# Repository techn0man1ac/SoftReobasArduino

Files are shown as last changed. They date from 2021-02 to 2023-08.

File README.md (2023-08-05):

# ATmega8/Arduino Nano reobas

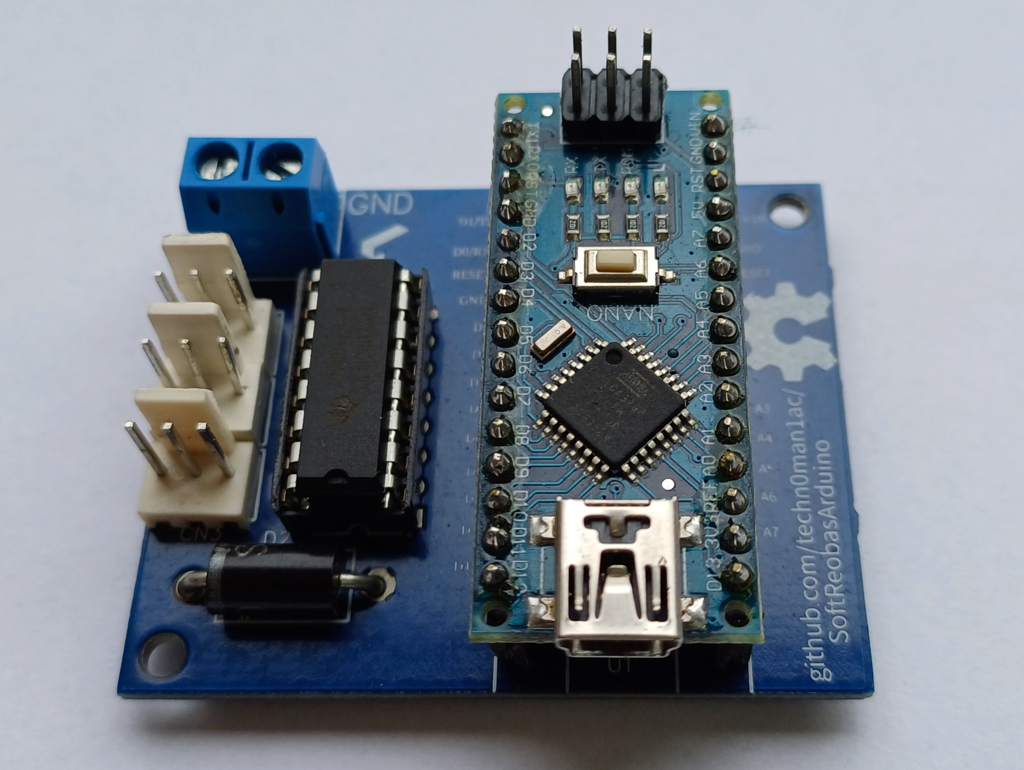
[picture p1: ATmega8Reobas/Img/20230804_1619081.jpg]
PCB board photo Board photo


This project is a controller for three standard PC fans, controlled by a computer program(Windows 7/10 tested). Video with a demonstration:

https://youtu.be/29GA7r1BqcI

# Schematic:

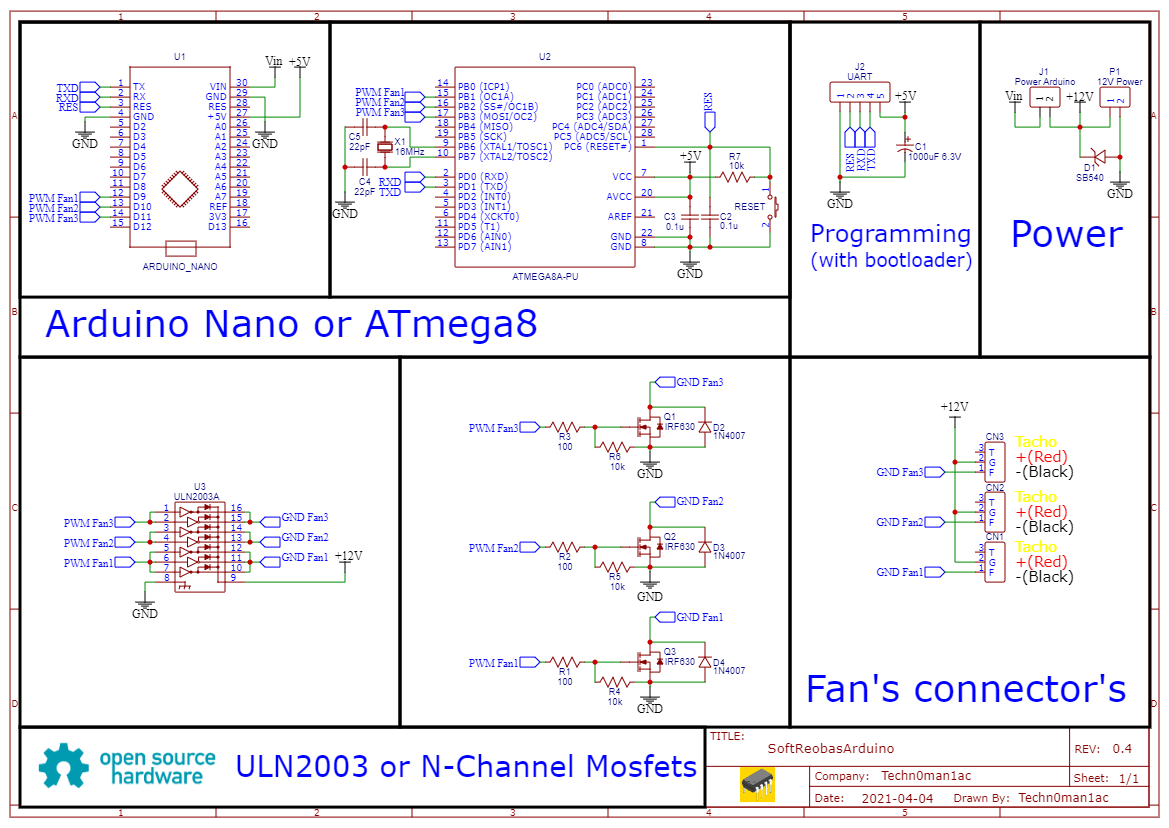
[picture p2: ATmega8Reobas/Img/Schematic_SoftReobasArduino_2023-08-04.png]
Schematic ATmega8/ArduinoNano


Schematics provide two versions of the board, one - using Arduino Nano and ULN2003(Darlington transistors package), first photo from upper, and second - using ATmega8 CPU and three MOSFET transistors in the TO-220 case(for example IRF540/IRF640/IRF740). 

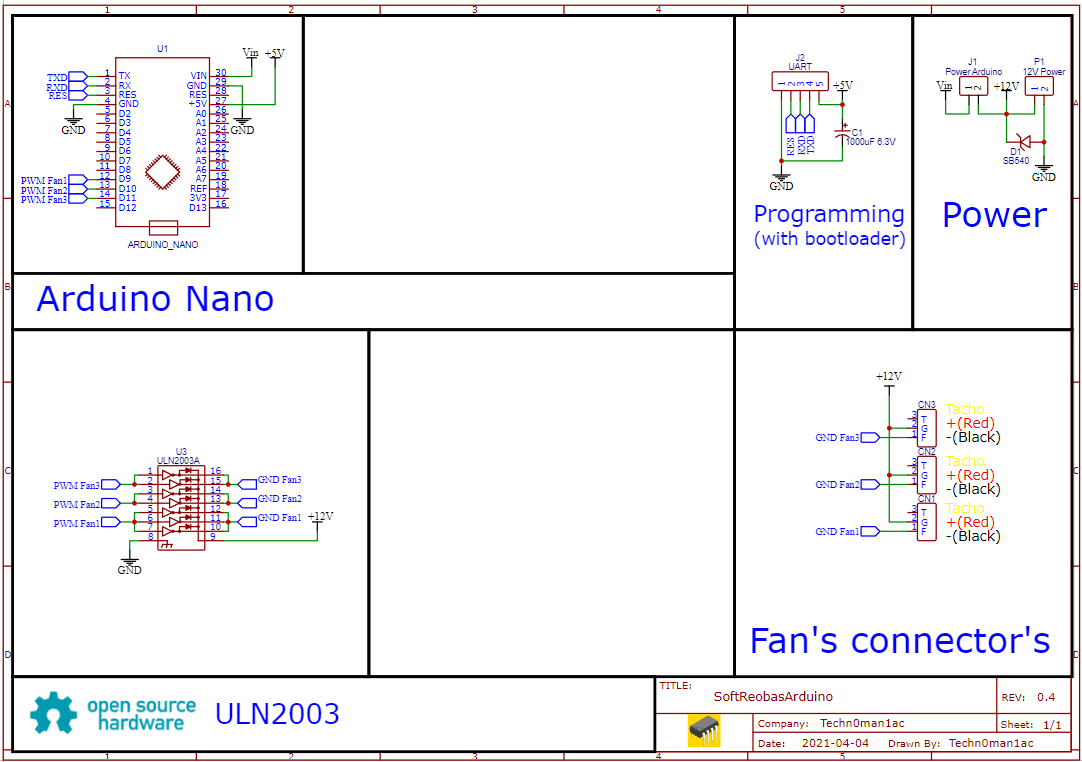
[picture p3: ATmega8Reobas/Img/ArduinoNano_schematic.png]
Schematic with ArduinoNano


I developed only the first one in PCB format, the second remained in prototype format(last photo). I like the first option because ULN2003 is popular chip that integrates everything from current-limiting resistors to protection diodes in a circuit that only requires a few components:

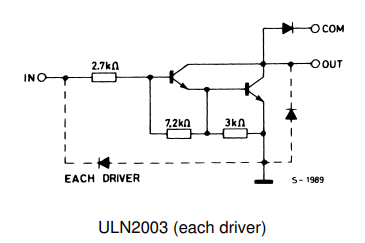
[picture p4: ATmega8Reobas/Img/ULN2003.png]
ULN2003 structure


According to the documentation for ULN2003, the chip can output 500mA per channel, if you look at my schematic, you will see that I have paralleled two outputs for the FAN2 and FAN3 - they can output up to 1000mA per fan, and fan1 has three outputs connected in parallel, correspondingly, the output current can be up to 1500 mA, that is, a more powerful fan can be connected here. However, MOSFET solutions can produce several times more output currents.

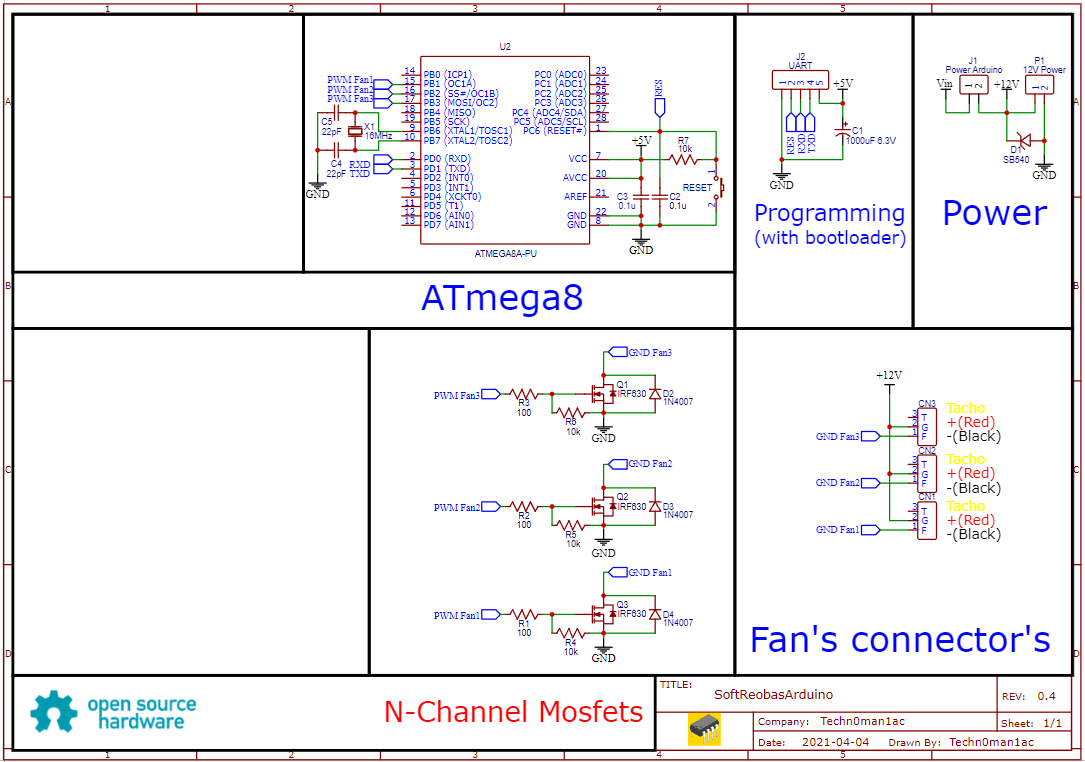
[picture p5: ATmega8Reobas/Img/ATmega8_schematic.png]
MOSFET solution


You can use both solutions, Arduino Nano or ATmega8, but in the case of ATmega8, you need pre-flash the firmware(with Arduino IDE) and next step - connect a USB-UART adapter to J2 (baud rate 9600), ATmega8 solutuon - need supply +5V for the J2, Arduino Nano have all this in board.

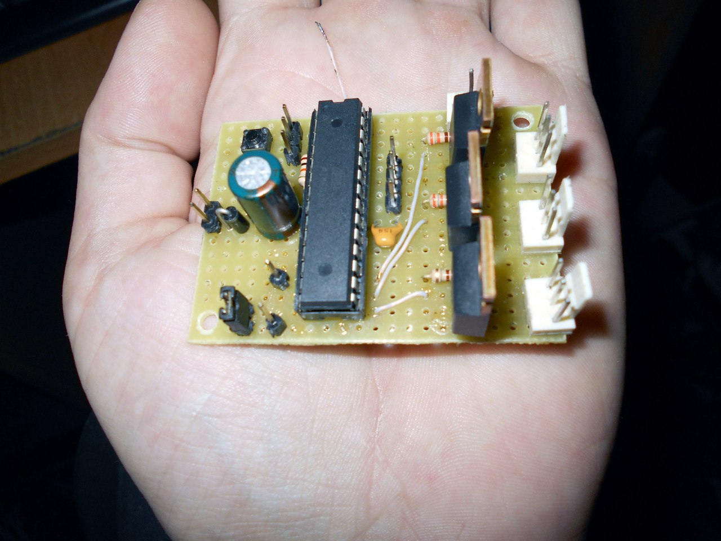
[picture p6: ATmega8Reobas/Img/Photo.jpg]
Schematic ATmega8/ArduinoNano


And last - in case ATmega8 you need to know how to Program an AVR Board Using an Arduino Board:

[https://www.instructables.com/How-to-program-a-AVR-arduino-with-another-arduin/](https://www.instructables.com/How-to-Program-an-AVR-Board-Using-an-Arduino-Board/)

# PCB:

The front:

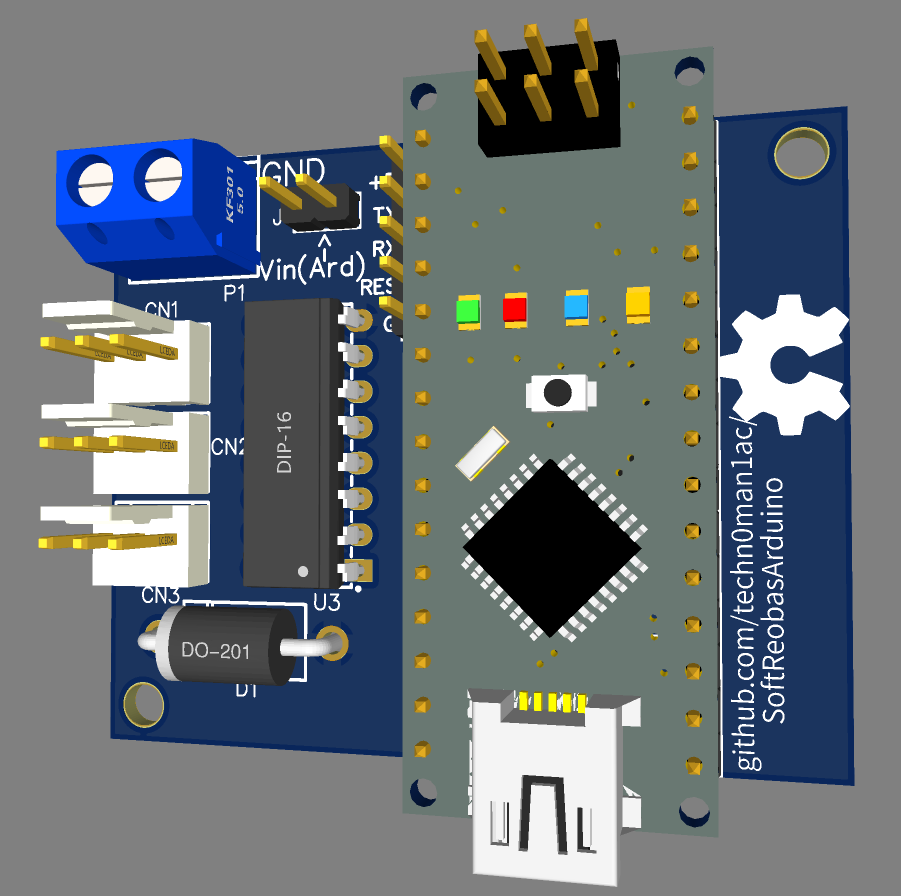
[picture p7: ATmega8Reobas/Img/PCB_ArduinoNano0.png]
ArduinoNano ULN2003 PCB render0


Bottom side:

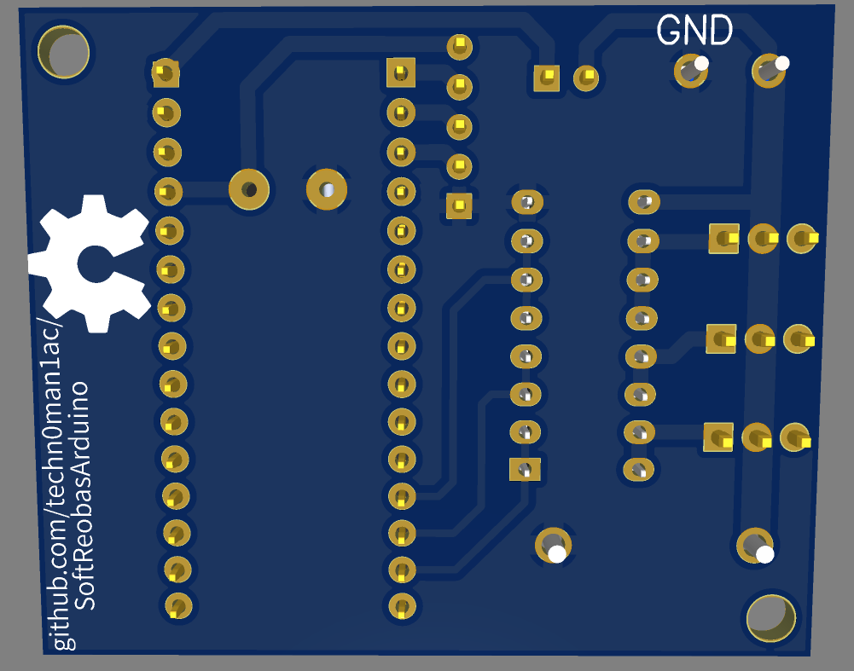
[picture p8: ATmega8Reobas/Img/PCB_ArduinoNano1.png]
ArduinoNano ULN2003 PCB render1


Board dimensions:

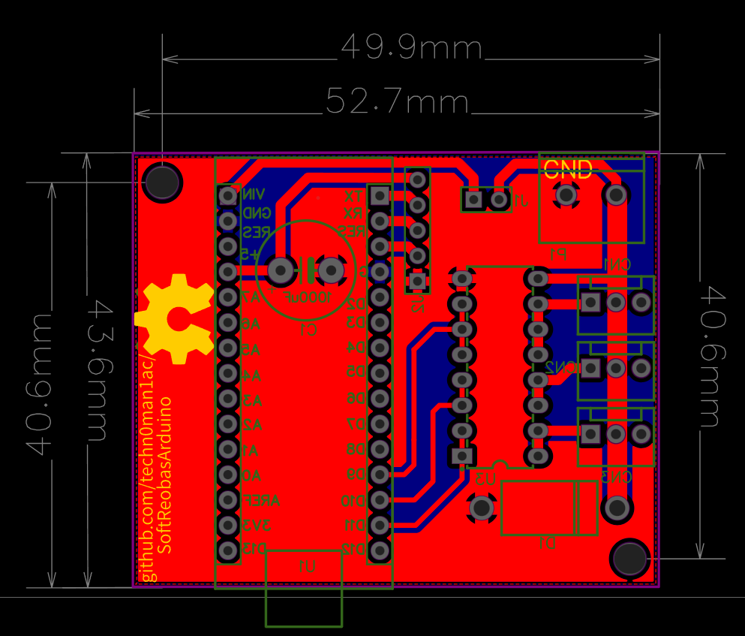
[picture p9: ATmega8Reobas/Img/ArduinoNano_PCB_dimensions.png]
ArduinoNano PCB dimensions ArduinoNano ArduinoNano PCB dimensions


Gerber files for order PCB here:

https://github.com/techn0man1ac/SoftReobasArduino/tree/main/ATmega8Reobas/PCB/Gerbers

Project (circuit and PCB) on EasyEDA(OSHWlab):

https://oshwlab.com/raznie.podelki/softreobasarduino

# Arduino IDE:

Source code for Arduino IDE:

https://github.com/techn0man1ac/SoftReobasArduino/tree/main/ATmega8Reobas/Code/Arduino%20IDE/SoftReobasArduino

As a CPU, you can use both, ATmega8 or Arduino Nano (by default, the code is selected for Arduino Nano, or ATmega328), if you use ATmega8 CPU, you need to comment out lines 15,16,18,19 and uncomment lines 24 and 25, as in the picture below:

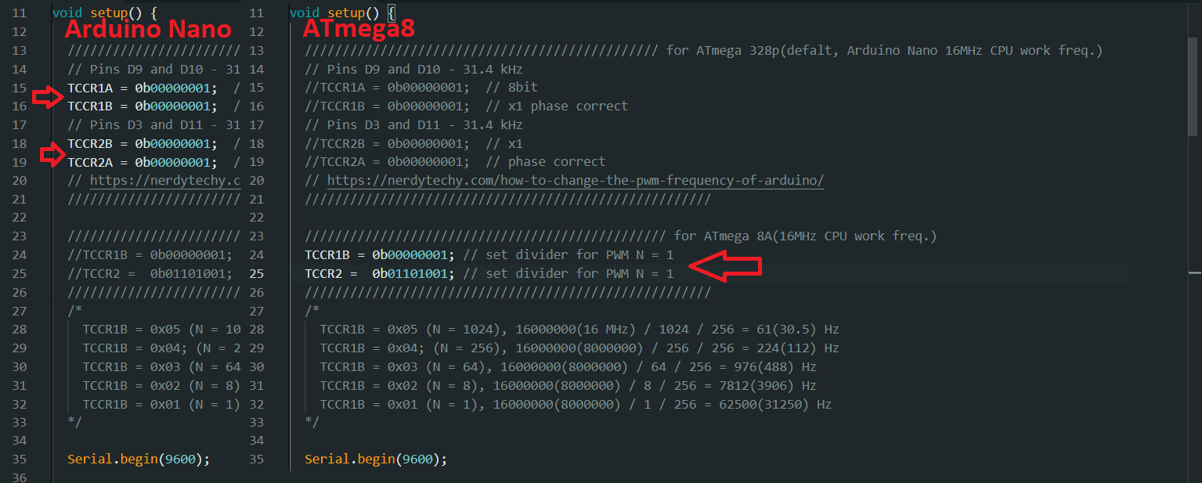
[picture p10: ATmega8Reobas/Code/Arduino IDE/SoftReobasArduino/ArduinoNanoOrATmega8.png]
ATmega8 or Arduino Nano ATmega8 or Arduino Nano


These lines set the PWM frequency at 31 kHz (so that the squeak of the fans is not heard), provided that the controller is clocked at a frequency of 16 MHz.
The only thing is that the ATmega8 must operate at a frequency of 16 MHz, that is, it must be clocked from an external quartz.

# Windows application:
 
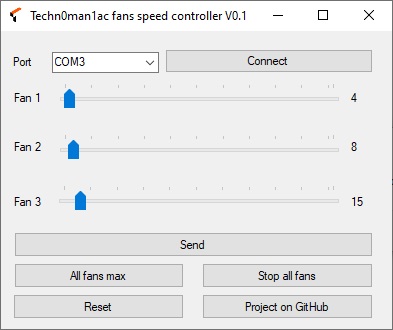
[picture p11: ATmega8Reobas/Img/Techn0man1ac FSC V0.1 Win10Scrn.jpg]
Windows10 screenshot app


The "Techn0man1ac FSC V0.1" program for PC (tested on Windows 7/10) works as - connect the board to the computer, run program and select "Port" in the drop-down list (top left), choose the number of the USB-UART COM port of the hardware converter, click " Connect" - well done, you can send commands to the board using the user interface buttons:
- "Send" - sends the current values set by the "Fan 1", "Fan 2", "Fan 3" sliders (default is 127, displayed to the right of the slider) to the microcontroller, which stores these values in its EEPROM (non-volatile memory), that is, even after restart the controller will remember this values;
- "All fans max" - this button gives the maximum speed for all fans (also written to EEPROM);
- "Stop all fans" - full stop(without write into EEPROM);
- "Reset" - restart the board;
- "Project on GitHub" - a button that brings the user here to the project page.

Download program "Techn0man1ac FSC V0.1":

https://github.com/techn0man1ac/ATmega8Reobas/tree/main/ATmega8Reobas/WinApp

# Protocol

The protocol of interaction is very simple - the program sends into COM every second the position of each slider in the format d127.64.255 and 127 is the speed of FAN1(CN1), 64 - FAN2(CN2), 255 - FAN3(CN3) but speed is 0..255 like 0..100%, where 255 is 100%.

- If program send "m" - presed button "All fans max";
- "s" - presed button "Stop all fans";
-  "r" - presed button "Reset".

CPU recognized its and do some magic - easy peasy, lemon squeeze ;)

# С# sourse code:

Program write on С# in "Microsoft Visual Studio Community 2019 V16.9.2", PS program source code - Fans speed controller(Windows):

https://github.com/techn0man1ac/ATmega8Reobas/tree/main/ATmega8Reobas/Code/Fans%20speed%20controller(Windows)/WindowsFormsApplication1

# Proteus 8 simulation:

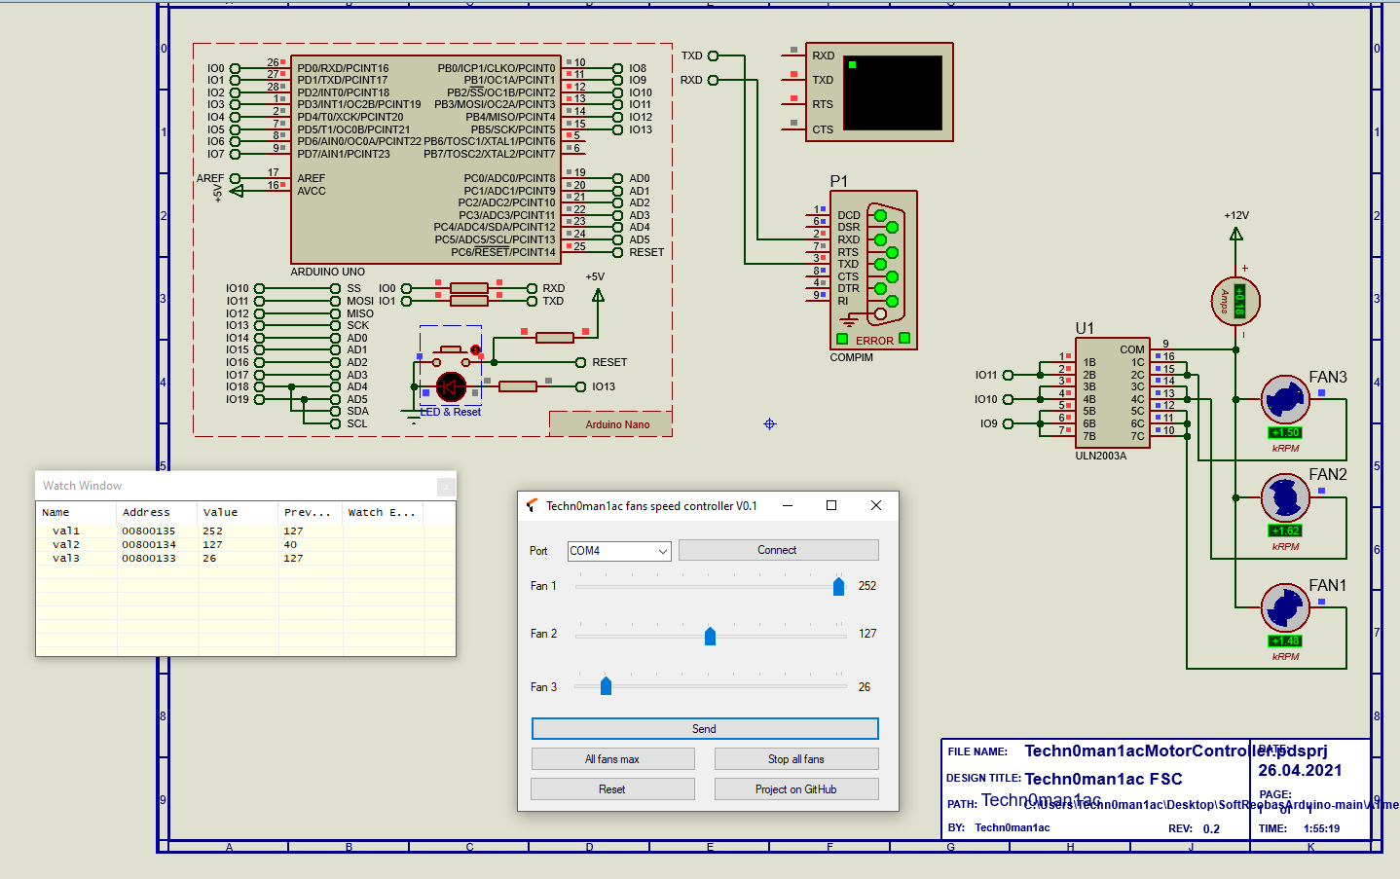
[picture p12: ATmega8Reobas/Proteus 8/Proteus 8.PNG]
Proteus 8 simulation


Project have Proteus 8 files and full simulate:

https://github.com/techn0man1ac/SoftReobasArduino/tree/main/ATmega8Reobas/Proteus%208

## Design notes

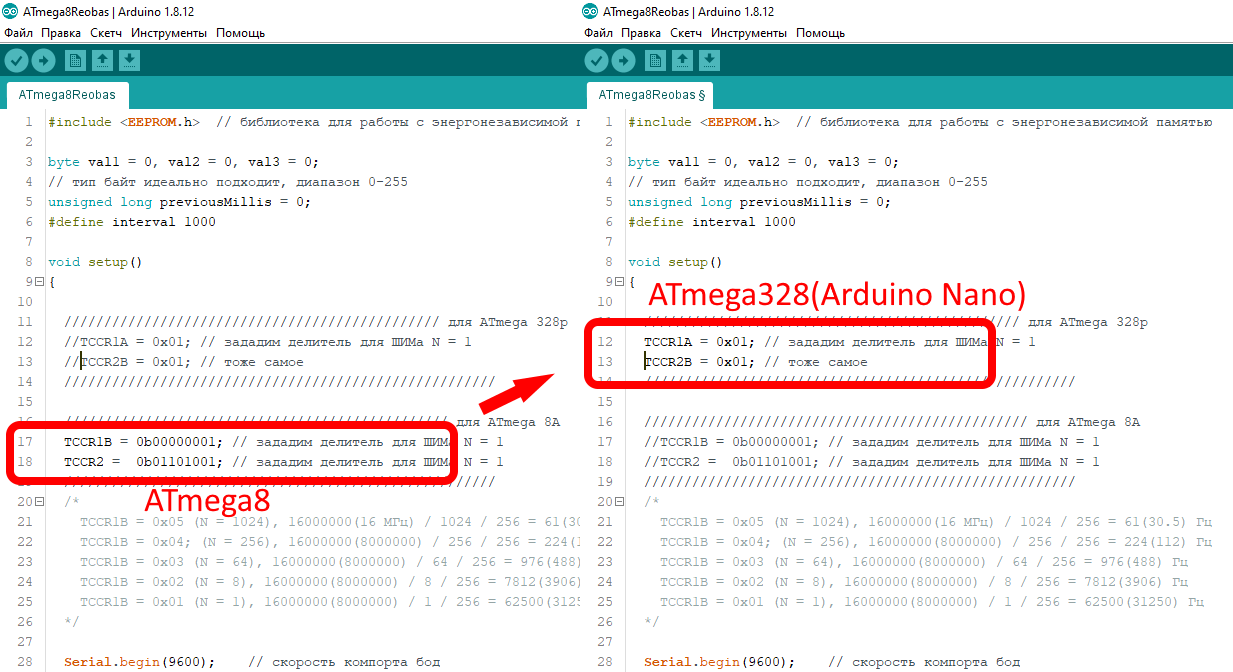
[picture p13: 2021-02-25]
ATmega8Reobas/Img/8or328.png

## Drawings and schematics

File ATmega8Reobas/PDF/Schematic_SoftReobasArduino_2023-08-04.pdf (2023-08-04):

A7 | 19 A6 | 20 A5 | 21 A4 | 22 A3 | 23 A2 | 24 A1 | 25 A0 | 26

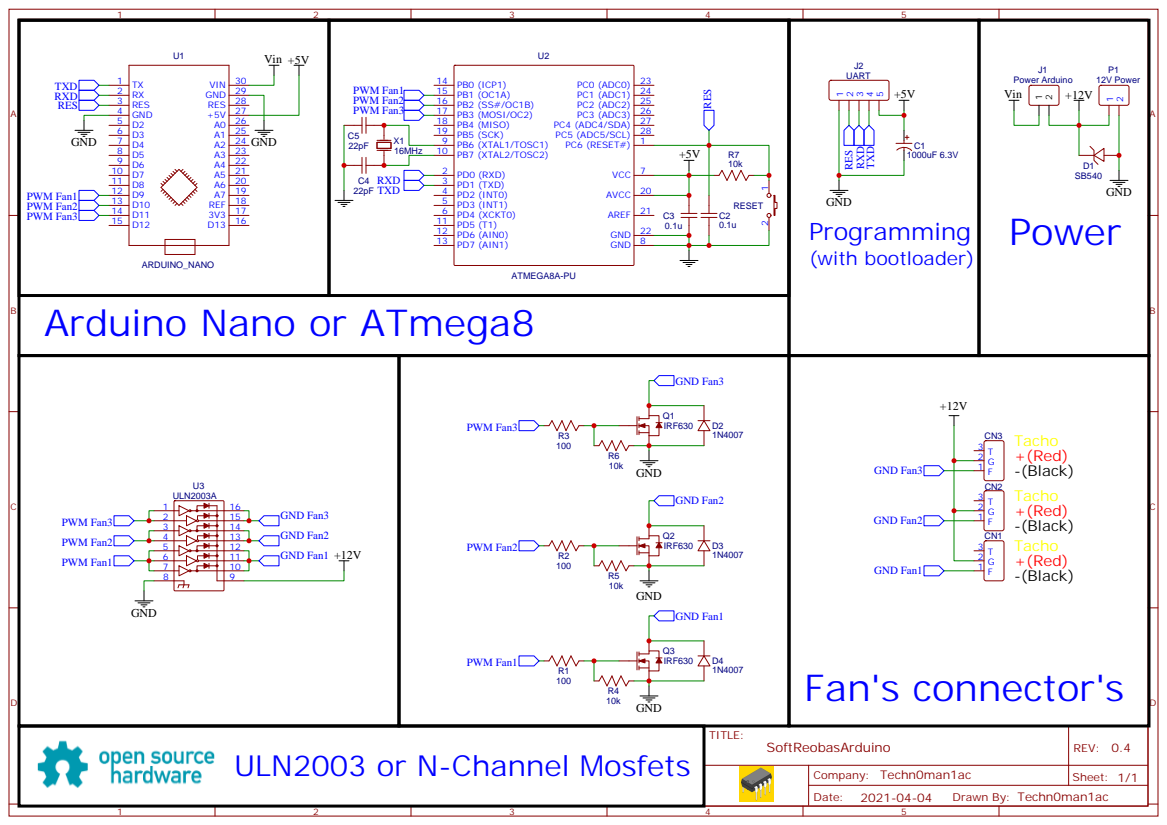
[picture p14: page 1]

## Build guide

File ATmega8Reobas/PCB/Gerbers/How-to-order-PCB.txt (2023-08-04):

How to Order PCB

Please refer to:
https://docs.easyeda.com/en/PCB/Order-PCB

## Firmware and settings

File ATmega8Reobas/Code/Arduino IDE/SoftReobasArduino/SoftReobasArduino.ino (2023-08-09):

// SoftReobasArduino By Serhii Trush for MIT License
// https://github.com/techn0man1ac/SoftReobasArduino/

#include <stdint.h>
#include <EEPROM.h>           // EEPROM librarry

#define INTERVAL_1S                     (1000)  // ewery 1 sec. work for datas
#define ZERO_FAN_SPEED                  (0)
#define MAX_FAN_SPEED                   (255)
#define UART_BAUDRATE                   (9600)
#define UART_SINGLE_CHAR_TIMEOUT_MS     (4)

uint8_t fan1Speed = ZERO_FAN_SPEED;
uint8_t fan2Speed = ZERO_FAN_SPEED;
uint8_t fan3Speed = ZERO_FAN_SPEED;  // byte type is ideal 0..255

uint32_t previousMillis = 0;

void setup() {

  /////////////////////////////////////////////// for ATmega 328p(defalt, Arduino Nano 16MHz CPU work freq.)
  // Pins D9 and D10 - 31.4 kHz
    TCCR1A = 0b00000001;  // 8bit
    TCCR1B = 0b00000001;  // x1 phase correct
    // Pins D3 and D11 - 31.4 kHz
    TCCR2B = 0b00000001;  // x1
    TCCR2A = 0b00000001;  // phase correct
  // https://nerdytechy.com/how-to-change-the-pwm-frequency-of-arduino/
  //////////////////////////////////////////////////////

  // TODO remove unused code

  //////////////////////////////////////////////// for ATmega 8А(16MHz CPU work freq.)
  // TCCR1B = 0b00000001; // set divider for PWM N = 1
  // TCCR2 =  0b01101001; // set divider for PWM N = 1
  //////////////////////////////////////////////////////
  /*
    TCCR1B = 0x05 (N = 1024), 16000000(16 MHz) / 1024 / 256 = 61(30.5) Hz
    TCCR1B = 0x04; (N = 256), 16000000(8000000) / 256 / 256 = 224(112) Hz
    TCCR1B = 0x03 (N = 64), 16000000(8000000) / 64 / 256 = 976(488) Hz
    TCCR1B = 0x02 (N = 8), 16000000(8000000) / 8 / 256 = 7812(3906) Hz
    TCCR1B = 0x01 (N = 1), 16000000(8000000) / 1 / 256 = 62500(31250) Hz
  */

    Serial.begin(UART_BAUDRATE);
    Serial.setTimeout(UART_SINGLE_CHAR_TIMEOUT_MS);  // time for one symbol is 4 ms - good working

    fan1Speed = EEPROM.read(1);  // Read EEPROM Memory
    fan2Speed = EEPROM.read(2);  // PWM duty cycle
    fan3Speed = EEPROM.read(3);  // Every fan have own EEPROM Memory value

    pinMode(9, OUTPUT);  // Fan1(CN1)
    pinMode(10, OUTPUT); // Fan2(CN2)
    pinMode(11, OUTPUT); // Fan3(CN3)

    digitalWrite(9, HIGH);  // force start all fans
    delay(2000);
    analogWrite(9, fan1Speed);  // set speed
    digitalWrite(10, HIGH);
    delay(2000);
    analogWrite(10, fan2Speed);  // 0..255(0..100%) - PWM duty cycle
    digitalWrite(11, HIGH);
    delay(2000);
    analogWrite(11, fan3Speed);

  /*
    You initialization here...
  */
}

void loop() {
    uint32_t currentMillis = millis();

    if (currentMillis - previousMillis > INTERVAL_1S) {
        previousMillis = currentMillis;

        if (Serial.available())  // if data receive
        {
            char data = Serial.read();

            switch (data) {
                case 'd':  // catch the symbol "d" and proceed to
                    fan1Speed = Serial.parseInt();  // receiving data(PWM duty cycle)
                    fan2Speed = Serial.parseInt();  // data must be in the format
                    fan3Speed = Serial.parseInt();  // d255.255.255 or, example d64.112.230

                    EEPROM.write(1, fan1Speed);  // write datas in
                    EEPROM.write(2, fan2Speed);  // non volatile memory(EEPROM)
                    EEPROM.write(3, fan3Speed);
                    delay(2000);  // important wait 2 seconds, for protect
                    break;

                case 'n':  // catch the symbol "n" - normal mode
                    fan1Speed = EEPROM.read(1);  // read what we have into EEPROM
                    fan2Speed = EEPROM.read(2);  // it's speed level
                    fan3Speed = EEPROM.read(3);
                    break;

                case 'm':  // catch the symbol "m" - max speed
                    fan1Speed = MAX_FAN_SPEED;
                    fan2Speed = MAX_FAN_SPEED;
                    fan3Speed = MAX_FAN_SPEED;
                    break;

                case 's':  // catch the symbol "s" - all stop
                    fan1Speed = ZERO_FAN_SPEED;
                    fan2Speed = ZERO_FAN_SPEED;
                    fan3Speed = ZERO_FAN_SPEED;
                    break;

                case 'r':  // catch the symbol "r" - board reboot
                    reboot();
                    break;

                default:
                    break; // unrecognized char
            }

            Serial.flush();  // clear buffer

            analogWrite(9, fan1Speed);  // set fans speed
            analogWrite(10, fan2Speed);
            analogWrite(11, fan3Speed);
        }

        Serial.print(fan1Speed);  // Transmit values of speed
        Serial.print(",");   // just for debug
        Serial.print(fan2Speed);
        Serial.print(",");
        Serial.println(fan3Speed);
    }
}

void reboot(){  // Reset function

  Serial.end();  // if necessary

  asm("cli");  // interrupts off

  // reset USART to reset defaults
#ifdef __AVR_ATmega8__
  UDR = 0;
  UCSRA = _BV(UDRE);
  UCSRB = 0;
  UCSRC = _BV(URSEL) | _BV(UCSZ1) | _BV(UCSZ0);
  UBRRL = 0;
  UBRRH = 0;
#else
  UDR0 = 0;
  UCSR0A = _BV(UDRE0);
  UCSR0B = 0;
  UCSR0C = _BV(UCSZ01) | _BV(UCSZ00);
  UBRR0L = 0;
  UBRR0H = 0;
#endif

  asm volatile("eor r1,r1");     // make sure zero-register is zero
  asm volatile("ldi r16,0xFF");  // end of RAM (0xFF)
  asm volatile("sts 0x5E,r16");  // SPH
  asm volatile("sts 0x5D,r16");  // SPL
  asm volatile("eor r31,r31");   // Clear Z register
  asm volatile("eor r30,r30");
  asm volatile("ijmp");  // jump to (Z)
}

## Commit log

2021-02-25 Update README.md
    Добавил описание проекта
2021-02-25 Update README.md
    ...ему нужен USB-UART преобразователь, можно взять готовую плату Arduino Nano, где он уже имеется на плате.
2021-02-25 Update README.md
    Добавил ссылку на ветку этого проекта на форуме Arduino
2021-02-25 Update README.md
    Add "бла бла бла"
2021-02-25 Update README.md
    Бла бла бла
2021-02-25 Update README.md
    Для перехода на Arduino Nano нужно...
2021-02-25 Add files via upload
    ATmega8 or Arduino Nano
2021-02-25 Update README.md
    Правки, боооольше правок
2021-02-25 Update README.md
    Бооольше правооок
2021-02-25 Add files via upload
    Add Schematic
2021-02-25 Update README.md
    Проект схемы на EasyEDA
2021-02-25 Update README.md
    Изменил структуру для более понятной
2021-02-25 Update README.md
    Переформатирую переструктурирую текст
2021-02-28 Create LICENSE
    Пользуйтесь
2021-03-06 Create LICENSE
    MIT наше всё
2021-03-28 Add files via upload
    Изменил иконку приложения и добавил Techn0man1ac логотип в программе(слева в углу), пересобрал проект в "Microsoft Visual Studio Community 2019
    Версия 16.9.2"
2021-03-28 Update README.md
    Добавил описание программы для ПК
2021-03-28 Update ATmega8Reobas.ino
    по умолчанию для Arduino Nano
2021-03-28 Update README.md
    Единственное, что, ATmega8 должна работать на частоте 16МГц, то есть тактироваться от внешнего кварца.
2021-03-29 Update LICENSE
    Пользуйтесь!
2021-03-31 Delete ATmega8Reobas/Code/Fans speed controller(Windows)/WindowsFormsApplication1/publish directory
    Мусор
2022-03-22 Change №001
    Add PCB screen
2022-03-22 Change №002
    Add PCB screen in README.md
2022-06-24 Change №003
    Fix PWM frequency for pins 9,10,11
2023-08-04 Change №003
    Add new schematic
2023-08-04 Change №004
    Add new PCB photo
2023-08-04 Change №005
    Add ATmega8 schematic only
2023-08-04 Change №006
    Add Arduino Nano schematic
2023-08-04 Change №007
    Add PCB renders
2023-08-04 Change №008
    Add ArduinoNano PCB dimensions
2023-08-04 Change №009
    Add gerber files and 3D model(*.obj)
    [Drill_PTH_Through.DRL, Drill_PTH_Through_Via.DRL, Gerber_BoardOutlineLayer.GKO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]
2023-08-04 Change №010
    Add project pdf files
2023-08-04 Change №011
    Add code and firmware(bin or hex files)
2023-08-04 Change №01
    Full translate into English
2023-08-04 Change №011
    Fully translate project into English, enjoy
2023-08-04 Change №012
    Add comments
    // Fan1(CN1)
    // Fan2(CN2)
    // Fan3(CN3)
2023-08-09 SoftReobasArduino.ino: refactoring, replace if-else by switch, eliminate magic numbers
    [SoftReobasArduino.ino]
2023-08-09 Change №013
    Accepted changes from @polesskiy-dev
    polesskiy-dev
